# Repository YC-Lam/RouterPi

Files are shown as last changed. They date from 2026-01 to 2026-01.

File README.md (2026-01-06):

# RouterPi

A modular router development board based on the raspberry pi compute module 5.

Features:
- 2x 2.5G Ethernet Wan/Lan port
- 2x Gigabyte Ethernet Lan port
- M.2 E key connector for AP module
- RTC battery
- PWM fan connector
- SD card slot for compute module lite
- 12-24v input voltage

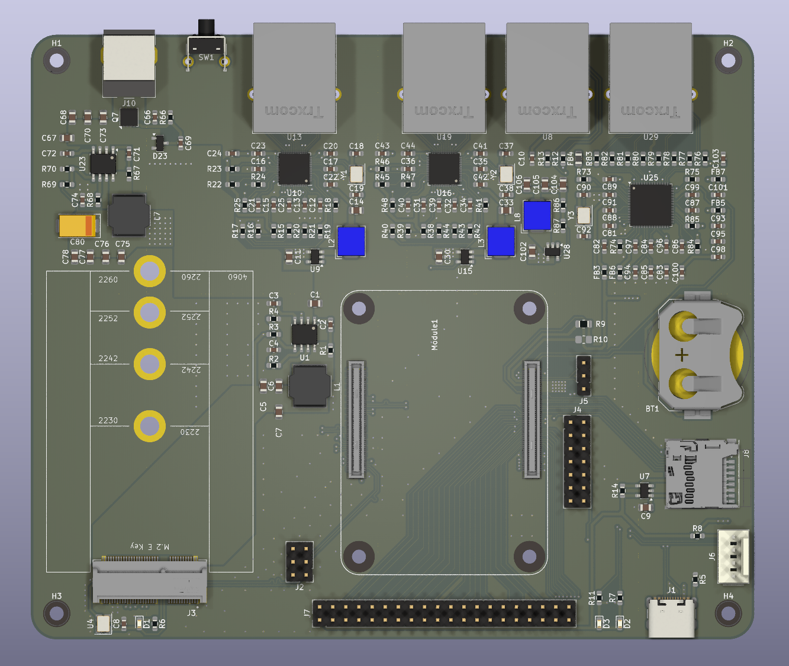
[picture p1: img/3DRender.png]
3D render


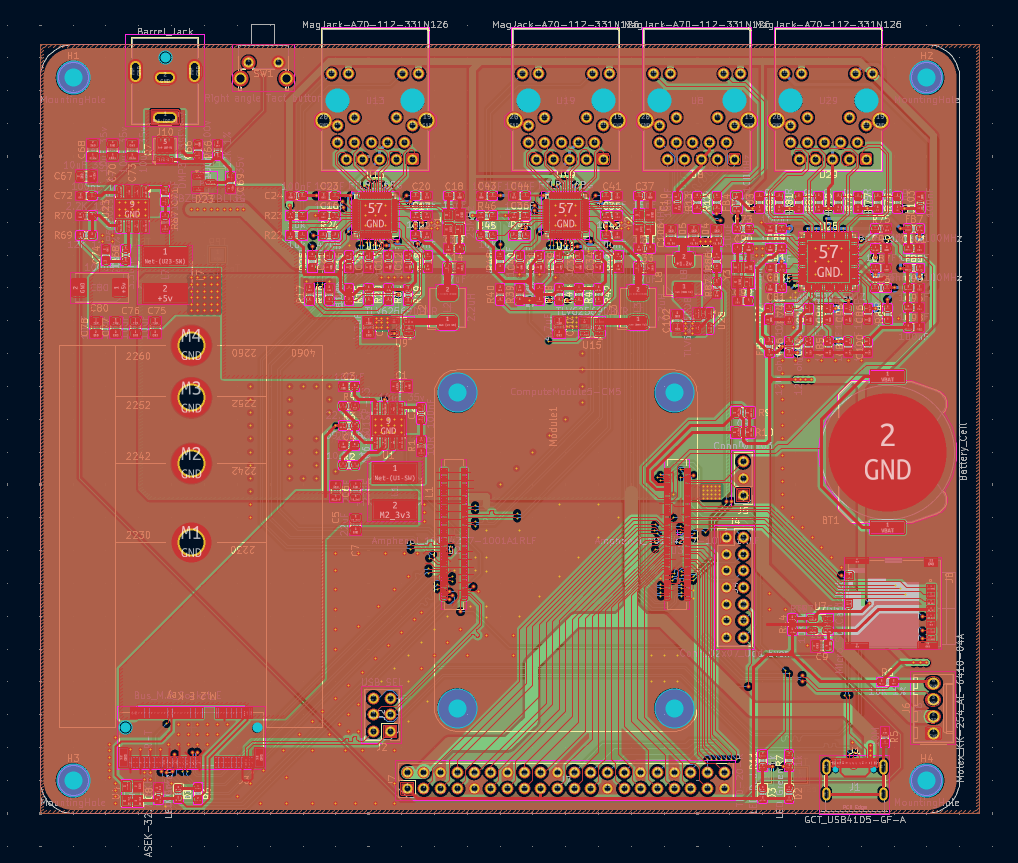
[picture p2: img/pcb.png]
PCB layout


# Design constraints
- minimal track width: 0.127 mm
- minimal clearance: 0.125 mm
- minimal via hole diameter: 0.3 mm
- minimal via ring diameter: 0.45 mm

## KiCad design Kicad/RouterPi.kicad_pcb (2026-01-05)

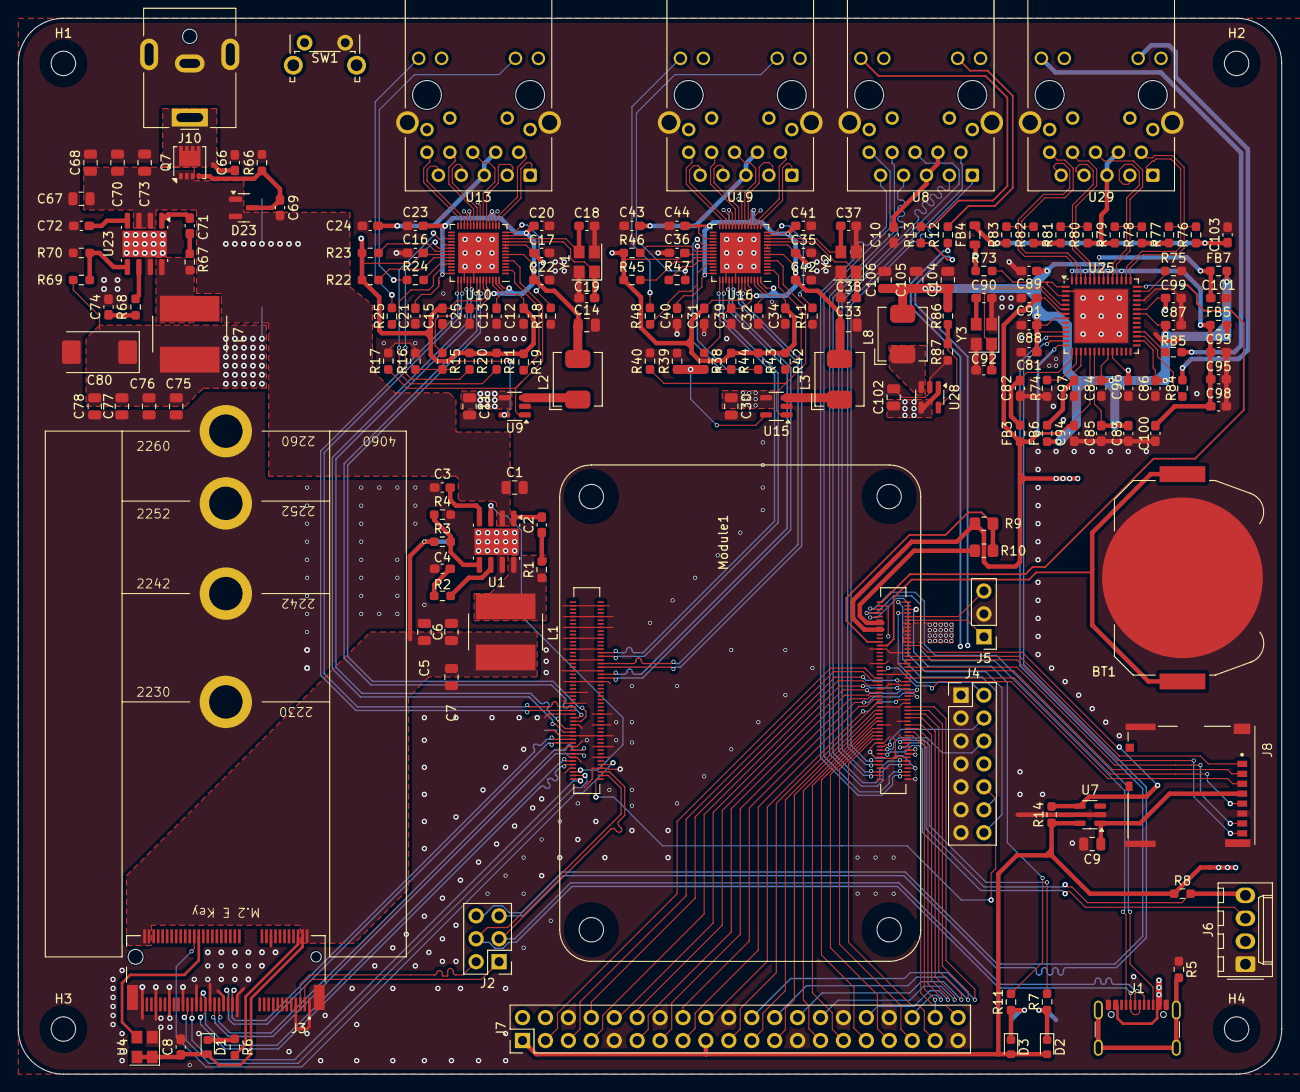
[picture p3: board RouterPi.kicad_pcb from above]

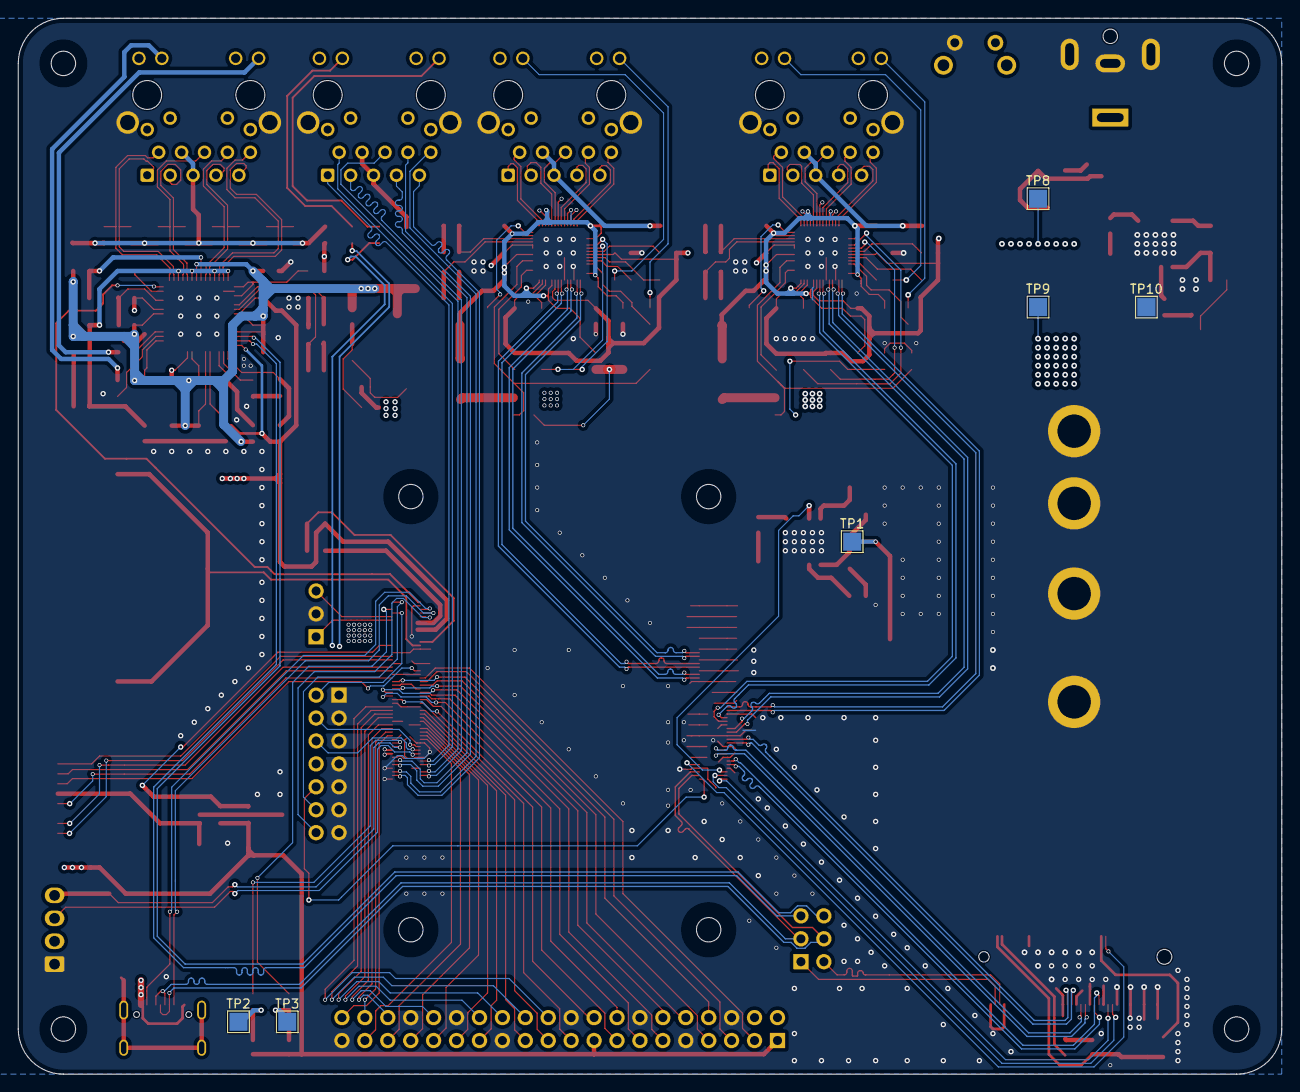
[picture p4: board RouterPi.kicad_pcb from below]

Board: 4 copper layers, 140.0 x 117.0 mm, 192 parts (6 on the bottom side), 199 nets.

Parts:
BT1: Battery_Cell; BatteryHolder_Keystone_3034_1x20mm
C1, C67, C68, C70, C73: 10uF 35v; C_0805_2012Metric
C2, C3, C8, C10, C12, C13, C15, C16, C17, C20, C21, C22, C23, C24, C25, C31, C32, C34, C35, C36, C39, C40, C41, C42, C43, C44, C71, C72, C81, C82, C83, C84, C85, C86, C87, C88, C89, C91, C93, C94, C95, C96, C97, C98, C99, C100, C101, C103: 100nF; C_0603_1608Metric_Pad1.08x0.95mm_HandSolder
C4: 2.7nF; C_0603_1608Metric_Pad1.08x0.95mm_HandSolder
C5, C6, C7: 22uF; C_0805_2012Metric
C9, C75, C76, C77, C78, C104, C105, C106: 10uF; C_0805_2012Metric
C11, C30, C102: 4.7uF; C_0805_2012Metric
C14, C33: 47uF; C_0805_2012Metric
C18, C19, C37, C38, C90, C92: 15pF; C_0603_1608Metric_Pad1.08x0.95mm_HandSolder
C66: 100nF 100v; C_0603_1608Metric_Pad1.08x0.95mm_HandSolder
C69: 100nF 35v; C_0603_1608Metric_Pad1.08x0.95mm_HandSolder
C74: 1.2nF; C_0603_1608Metric_Pad1.08x0.95mm_HandSolder
C80: 100uF; CP_EIA-7343-31_Kemet-D
D1, D2: LED Green; LED_0603_1608Metric
D3: LED Red; LED_0603_1608Metric
D23: MMBZ5242BLT3G; SOT-23
FB3, FB5, FB6, FB7: 120 ohms@100MHz; R_0603_1608Metric_Pad0.98x0.95mm_HandSolder
FB4: 220 ohms@100MHz; L_0805_2012Metric
H1, H2, H3, H4: MountingHole; MountingHole_2.7mm_M2.5_DIN965
J1: GCT_USB4105-GF-A; USB_C_Receptacle_GCT_USB4105-xx-A_16P_TopMnt_Horizontal
J2: USB SEL; PinHeader_2x03_P2.54mm_Vertical
J3: Bus_M.2_Socket_E; AMPHENOL_MDT420E03001
J4: Conn_02x07_Odd_Even; PinHeader_2x07_P2.54mm_Vertical
J5: Conn_01x03; PinHeader_1x03_P2.54mm_Vertical
J6: Molex_KK-254_AE-6410-04A; Molex_KK-254_AE-6410-04A_1x04_P2.54mm_Vertical
J7: THD-20-R; PinHeader_2x20_P2.54mm_Vertical
J8: Micro_SD_Card_Det; SDCARD_MOLEX_503398-1892
J10: Barrel_Jack; BarrelJack_CUI_PJ-063AH_Horizontal
L1, L7: 3.3uH; L_Bourns_SRN8040TA
L2, L3, L8: 2.2uH; L_Bourns_SRP5030CC
Module1: ComputeModule5-CM5; Raspberry-Pi-5-Compute-Module
Q7: DMP3013SFV-7; Diodes_PowerDI3333-8
R1, R67: 10R; R_0603_1608Metric_Pad0.98x0.95mm_HandSolder
R2: 10.5k 1%; R_0603_1608Metric_Pad0.98x0.95mm_HandSolder
R3: 69.8K 1%; R_0603_1608Metric_Pad0.98x0.95mm_HandSolder
R4: 22.1K 1%; R_0603_1608Metric_Pad0.98x0.95mm_HandSolder
R5: 10M; R_0603_1608Metric_Pad0.98x0.95mm_HandSolder
R6, R7, R11: 1k; R_0603_1608Metric_Pad0.98x0.95mm_HandSolder
R8, R14: 10K 1%; R_0603_1608Metric_Pad0.98x0.95mm_HandSolder
R9: 0R; R_0805_2012Metric_Pad1.20x1.40mm_HandSolder
R10: nf; R_0805_2012Metric_Pad1.20x1.40mm_HandSolder
R12, R13, R24, R25, R47, R48, R84, R85: 470R; R_0603_1608Metric_Pad0.98x0.95mm_HandSolder
R15, R38: 57.6k; R_0603_1608Metric_Pad0.98x0.95mm_HandSolder
R16, R39, R86, R87: 100k; R_0603_1608Metric_Pad0.98x0.95mm_HandSolder
R17, R19, R20, R21, R22, R23, R40, R42, R43, R44, R45, R46, R73: 10k; R_0603_1608Metric_Pad0.98x0.95mm_HandSolder
R18, R41: 2.49k; R_0603_1608Metric_Pad0.98x0.95mm_HandSolder
R66, R69: 12K 1%; R_0603_1608Metric_Pad0.98x0.95mm_HandSolder
R68: 20K 1%; R_0603_1608Metric_Pad0.98x0.95mm_HandSolder
R70: 2.2K 1%; R_0603_1608Metric_Pad0.98x0.95mm_HandSolder
R74: 12k 1%; R_0603_1608Metric_Pad0.98x0.95mm_HandSolder
R75: 8.06k 1%; R_0603_1608Metric_Pad0.98x0.95mm_HandSolder
R76, R77, R78, R79, R80, R81, R82, R83: 49.9R; R_0603_1608Metric_Pad0.98x0.95mm_HandSolder
SW1: Right angle Tact button; SW_Tactile_SPST_Angled_PTS645Vx58-2LFS
TP1, TP2, TP3, TP8, TP9, TP10: TestPoint; TestPoint_Pad_2.0x2.0mm
U1, U23: AP64501SP-13; SOIC-8-1EP_3.9x4.9mm_P1.27mm_EP2.95x4.9mm_Mask2.71x3.4mm
U2, U3: Amphenol_10164227-1001A1RLF; Amphenol_10164227-1001A1RLF_placeholder
U4: ASEK-32.768KHZ-L-R-T; Crystal_SMD_3225-4Pin_3.2x2.5mm
U7: RT9742GGJ5; SOT-23-5
U8, U13, U19, U29: MagJack-A70-112-331N126; TRJG0926HENL
U9, U15, U28: TLV62569DBVR; SOT-23-5
U10, U16: RTL8156BG; QFN-56_EP_6x6_Pitch0.35mm
U25: LAN7500-ABJZ; QFN-56-1EP_8x8mm_P0.5mm_EP5.9x5.9mm
Y1, Y2, Y3: 25MHz; Crystal_SMD_3225-4Pin_3.2x2.5mm

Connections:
/2.5G_ETHERNET_LAN/DVDD09: C33.1, C39.1, C40.1, C41.1, C42.1, C44.1, L3.2, R38.1, U16.7 (DVDD09), U16.13 (AVDD09), U16.18 (AVDD09), U16.24 (AVDD09), U16.31 (DVDD09), U16.42 (VDD09_USB), U16.52 (VDD09_USB), U16.56 (DVDD09)
/2.5G_ETHERNET_LAN/DVDD09_EN: R40.1, U15.1 (EN), U16.5 (POW_EXT_SWR)
/2.5G_ETHERNET_LAN/ETH_LEDG: R47.2, U16.38 (LED0/EEDI/SPISI)
/2.5G_ETHERNET_LAN/ETH_LEDY: R48.2, U16.39 (LED1/EESK/SPISCK)
/2.5G_ETHERNET_LAN/TRD0_N: U16.16 (MDIN0), U19.2 (TRD0-)
/2.5G_ETHERNET_LAN/TRD0_P: U16.15 (MDIP0), U19.1 (TRD0+)
/2.5G_ETHERNET_LAN/TRD1_N: U16.20 (MDIN1), U19.6 (TRD1-)
/2.5G_ETHERNET_LAN/TRD1_P: U16.19 (MDIP1), U19.3 (TRD1+)
/2.5G_ETHERNET_LAN/TRD2_N: U16.23 (MDIN2), U19.8 (TRD2-)
/2.5G_ETHERNET_LAN/TRD2_P: U16.22 (MDIP2), U19.7 (TRD2+)
/2.5G_ETHERNET_LAN/TRD3_N: U16.27 (MDIN3), U19.10 (TRD3-)
/2.5G_ETHERNET_LAN/TRD3_P: U16.26 (MDIP3), U19.9 (TRD3+)
/2.5G_ETHERNET_LAN/USB3_D_N: Module1.165 (USB3-1-D_N), U16.49 (DM)
/2.5G_ETHERNET_LAN/USB3_D_P: Module1.163 (USB3-1-D_P), U16.50 (DP)
/2.5G_ETHERNET_LAN/USB3_RXN: Module1.157 (USB3-1-RX_N), U16.47 (SSRXN)
/2.5G_ETHERNET_LAN/USB3_RXP: Module1.159 (USB3-1-RX_P), U16.46 (SSRXP)
/2.5G_ETHERNET_LAN/USB3_TXN: Module1.169 (USB3-1-TX_N), U16.44 (SSTXN)
/2.5G_ETHERNET_LAN/USB3_TXP: Module1.171 (USB3-1-TX_P), U16.43 (SSTXP)
/2.5G_ETHERNET_LAN/XIN: C37.1, U16.12 (CKXTAL1), Y2.3
/2.5G_ETHERNET_LAN/XOUT: C38.1, U16.11 (CKXTAL2), Y2.1
/2.5G_ETHERNET_WAN/DVDD09: C14.1, C20.1, C21.1, C22.1, C23.1, C25.1, L2.2, R15.1, U10.7 (DVDD09), U10.13 (AVDD09), U10.18 (AVDD09), U10.24 (AVDD09), U10.31 (DVDD09), U10.42 (VDD09_USB), U10.52 (VDD09_USB), U10.56 (DVDD09)
/2.5G_ETHERNET_WAN/DVDD09_EN: R17.1, U9.1 (EN), U10.5 (POW_EXT_SWR)
/2.5G_ETHERNET_WAN/ETH_LEDG: R24.2, U10.38 (LED0/EEDI/SPISI)
/2.5G_ETHERNET_WAN/ETH_LEDY: R25.2, U10.39 (LED1/EESK/SPISCK)
/2.5G_ETHERNET_WAN/TRD0_N: U10.16 (MDIN0), U13.2 (TRD0-)
/2.5G_ETHERNET_WAN/TRD0_P: U10.15 (MDIP0), U13.1 (TRD0+)
/2.5G_ETHERNET_WAN/TRD1_N: U10.20 (MDIN1), U13.6 (TRD1-)
/2.5G_ETHERNET_WAN/TRD1_P: U10.19 (MDIP1), U13.3 (TRD1+)
/2.5G_ETHERNET_WAN/TRD2_N: U10.23 (MDIN2), U13.8 (TRD2-)
/2.5G_ETHERNET_WAN/TRD2_P: U10.22 (MDIP2), U13.7 (TRD2+)
/2.5G_ETHERNET_WAN/TRD3_N: U10.27 (MDIN3), U13.10 (TRD3-)
/2.5G_ETHERNET_WAN/TRD3_P: U10.26 (MDIP3), U13.9 (TRD3+)
/2.5G_ETHERNET_WAN/USB3_D_N: Module1.136 (USB3-0-D_N), U10.49 (DM)
/2.5G_ETHERNET_WAN/USB3_D_P: Module1.134 (USB3-0-D_P), U10.50 (DP)
/2.5G_ETHERNET_WAN/USB3_RXN: Module1.130 (USB3-0-RX_P), U10.47 (SSRXN)
/2.5G_ETHERNET_WAN/USB3_RXP: Module1.128 (USB3-0-RX_N), U10.46 (SSRXP)
/2.5G_ETHERNET_WAN/USB3_TXN: Module1.142 (USB3-0-TX_P), U10.44 (SSTXN)
/2.5G_ETHERNET_WAN/USB3_TXP: Module1.140 (USB3-0-TX_N), U10.43 (SSTXP)
/2.5G_ETHERNET_WAN/XIN: C18.1, U10.12 (CKXTAL1), Y1.3
/2.5G_ETHERNET_WAN/XOUT: C19.1, U10.11 (CKXTAL2), Y1.1
/1000M_ETHERNET_LAN/+1.2v: C81.1, C83.1, C84.1, C85.1, C86.1, C87.1, C88.1, C89.1, C104.1, C105.1, C106.1, FB5.2, FB6.1, FB7.2, L8.2, R86.1, U25.8 (VDD12CORE), U25.11 (VDD12CORE), U25.20 (VDD12CORE), U25.23 (VDD12CORE), U25.30 (VDD12CORE), U25.36 (VDD12CORE), U25.49 (VDD12BIAS)
/1000M_ETHERNET_LAN/CT: C103.1, FB4.2, R76.1, R77.1, R78.1, R79.1, R80.1, R81.1, R82.1, R83.1, U29.4 (CT), U29.5 (CT)
/1000M_ETHERNET_LAN/ETH_LEDG: R84.2, U25.31 (GPIO0)
/1000M_ETHERNET_LAN/ETH_LEDY: R85.2, U25.32 (GPIO1)
/1000M_ETHERNET_LAN/TRD0_N: R76.2, U25.43 (TR0N), U29.2 (TRD0-)
/1000M_ETHERNET_LAN/TRD0_P: R77.2, U25.44 (TR0P), U29.1 (TRD0+)
/1000M_ETHERNET_LAN/TRD1_N: R78.2, U25.46 (TR1N), U29.6 (TRD1-)
/1000M_ETHERNET_LAN/TRD1_P: R79.2, U25.47 (TR1P), U29.3 (TRD1+)
/1000M_ETHERNET_LAN/TRD2_N: R80.2, U25.51 (TR2N), U29.8 (TRD2-)
/1000M_ETHERNET_LAN/TRD2_P: R81.2, U25.52 (TR2P), U29.7 (TRD2+)
/1000M_ETHERNET_LAN/TRD3_N: R82.2, U25.54 (TR3N), U29.10 (TRD3-)
/1000M_ETHERNET_LAN/TRD3_P: R83.2, U25.55 (TR3P), U29.9 (TRD3+)
/1000M_ETHERNET_LAN/USB2_D_N: J2.6, U25.12 (USBDM)
/1000M_ETHERNET_LAN/USB2_D_P: J2.5, U25.13 (USBDP)
/1000M_ETHERNET_LAN/VDD12A: C93.1, C95.1, C98.1, C100.1, FB5.1, U25.45 (VDD12A), U25.48 (VDD12A), U25.53 (VDD12A), U25.56 (VDD12A)
/1000M_ETHERNET_LAN/VDD12PLL: C101.1, FB7.1, U25.50 (VDD12PLL)
/1000M_ETHERNET_LAN/VDD12USBPLL: C97.1, FB6.2, U25.17 (VDD12USBPLL)
/1000M_ETHERNET_LAN/XIN: C90.1, U25.5 (XI), Y3.3
/1000M_ETHERNET_LAN/XOUT: C92.1, U25.6 (XO), Y3.1
/+3.3v: C12.1, C15.1, C16.1, C17.1, C31.1, C34.1, C35.1, C36.1, C91.1, C94.1, C96.1, C99.1, D2.2 (A), D3.2 (A), FB3.1, FB4.1, J7.1, J7.17, Module1.84 (+3.3v_(Output)), Module1.86 (+3.3v_(Output)), R8.1, R9.1, R14.1, R19.1, R20.1, R21.1, R22.1, R23.1, R42.1, R43.1, R44.1, R45.1, R46.1, R73.1, U7.5 (IN), U8.15 (LEDY_A), U8.17 (LEDG_A), U10.9 (AVDD33), U10.10 (AVDD33_XTAL), U10.17 (AVDD33), U10.21 (AVDD33), U10.25 (AVDD33), U10.36 (DVDD33), U10.51 (VDD33_USB), U10.55 (DVDD33_UPS), U13.15 (LEDY_A), U13.17 (LEDG_A), U16.9 (AVDD33), U16.10 (AVDD33_XTAL), U16.17 (AVDD33), U16.21 (AVDD33), U16.25 (AVDD33), U16.36 (DVDD33), U16.51 (VDD33_USB), U16.55 (DVDD33_UPS), U19.15 (LEDY_A), U19.17 (LEDG_A), U25.7 (VDDVARIO), U25.14 (VBUS_DET), U25.19 (VDDVARIO), U25.24 (VDDVARIO), U25.37 (VDDVARIO), U29.15 (LEDY_A), U29.17 (LEDG_A)
/+5v: C11.1, C30.1, C75.1, C76.1, C77.1, C78.1, C80.1, C102.1, J1.A4 (VBUS), J1.A9 (VBUS), J1.B4 (VBUS), J1.B9 (VBUS), J7.2, J7.4, L7.2, Module1.77 (+5v_(Input)), Module1.79 (+5v_(Input)), Module1.81 (+5v_(Input)), Module1.83 (+5v_(Input)), Module1.85 (+5v_(Input)), Module1.87 (+5v_(Input)), R69.1, TP9.1, U9.4 (VIN), U15.4 (VIN), U28.1 (EN), U28.4 (VIN)
/+12v: C1.1, C67.1, C68.1, C69.1, C70.1, C73.1, D23.1 (K), D23.2 (K), J6.2, Q7.1 (S), Q7.2 (S), Q7.3 (S), TP8.1, U1.2 (VIN), U23.2 (VIN), U23.3 (EN)
/CM5_GPIO ( Ethernet, GPIO, SDCARD)/+1.8v: Module1.88 (+1.8v_(Output)), Module1.90 (+1.8v_(Output)), R10.1
/CM5_GPIO ( Ethernet, GPIO, SDCARD)/BT_nDis: J5.3, Module1.91 (BT_nDisable)
/CM5_GPIO ( Ethernet, GPIO, SDCARD)/CC1: J1.A5 (CC1), Module1.94 (CC1)
/CM5_GPIO ( Ethernet, GPIO, SDCARD)/CC2: J1.B5 (CC2), Module1.96 (CC2)
/CM5_GPIO ( Ethernet, GPIO, SDCARD)/EEPROM_nWP: J4.4, Module1.20 (EEPROM_nWP)
/CM5_GPIO ( Ethernet, GPIO, SDCARD)/ETH_LEDG: Module1.17 (Ethernet_nLED2(3.3v)), R12.2
/CM5_GPIO ( Ethernet, GPIO, SDCARD)/ETH_LEDY: Module1.15 (Ethernet_nLED3(3.3v)), R13.2
/CM5_GPIO ( Ethernet, GPIO, SDCARD)/GPIO2: J7.3, Module1.58 (GPIO2)
/CM5_GPIO ( Ethernet, GPIO, SDCARD)/GPIO3: J7.5, Module1.56 (GPIO3)
/CM5_GPIO ( Ethernet, GPIO, SDCARD)/GPIO4: J7.7, Module1.54 (GPIO4)
/CM5_GPIO ( Ethernet, GPIO, SDCARD)/GPIO5: J7.29, Module1.34 (GPIO5)
/CM5_GPIO ( Ethernet, GPIO, SDCARD)/GPIO6: J7.31, Module1.30 (GPIO6)
/CM5_GPIO ( Ethernet, GPIO, SDCARD)/GPIO7: J7.26, Module1.37 (GPIO7)
/CM5_GPIO ( Ethernet, GPIO, SDCARD)/GPIO8: J7.24, Module1.39 (GPIO8)
/CM5_GPIO ( Ethernet, GPIO, SDCARD)/GPIO9: J7.21, Module1.40 (GPIO9)
/CM5_GPIO ( Ethernet, GPIO, SDCARD)/GPIO10: J7.19, Module1.44 (GPIO10)
/CM5_GPIO ( Ethernet, GPIO, SDCARD)/GPIO11: J7.23, Module1.38 (GPIO11)
/CM5_GPIO ( Ethernet, GPIO, SDCARD)/GPIO12: J7.32, Module1.31 (GPIO12)
/CM5_GPIO ( Ethernet, GPIO, SDCARD)/GPIO13: J7.33, Module1.28 (GPIO13)
/CM5_GPIO ( Ethernet, GPIO, SDCARD)/GPIO14: J7.8, Module1.55 (GPIO14)
/CM5_GPIO ( Ethernet, GPIO, SDCARD)/GPIO15: J7.10, Module1.51 (GPIO15)
/CM5_GPIO ( Ethernet, GPIO, SDCARD)/GPIO16: J7.36, Module1.29 (GPIO16)
/CM5_GPIO ( Ethernet, GPIO, SDCARD)/GPIO17: J7.11, Module1.50 (GPIO17)
/CM5_GPIO ( Ethernet, GPIO, SDCARD)/GPIO18: J7.12, Module1.49 (GPIO18)
/CM5_GPIO ( Ethernet, GPIO, SDCARD)/GPIO19: J7.35, Module1.26 (GPIO19)
/CM5_GPIO ( Ethernet, GPIO, SDCARD)/GPIO20: J7.38, Module1.27 (GPIO20)
/CM5_GPIO ( Ethernet, GPIO, SDCARD)/GPIO21: J7.40, Module1.25 (GPIO21)
/CM5_GPIO ( Ethernet, GPIO, SDCARD)/GPIO22: J7.15, Module1.46 (GPIO22)
/CM5_GPIO ( Ethernet, GPIO, SDCARD)/GPIO23: J7.16, Module1.47 (GPIO23)
/CM5_GPIO ( Ethernet, GPIO, SDCARD)/GPIO24: J7.18, Module1.45 (GPIO24)
/CM5_GPIO ( Ethernet, GPIO, SDCARD)/GPIO25: J7.22, Module1.41 (GPIO25)
/CM5_GPIO ( Ethernet, GPIO, SDCARD)/GPIO26: J7.37, Module1.24 (GPIO26)
/CM5_GPIO ( Ethernet, GPIO, SDCARD)/GPIO27: J7.13, Module1.48 (GPIO27)
/CM5_GPIO ( Ethernet, GPIO, SDCARD)/GPIO_VREF: Module1.78 (GPIO_VREF(1.8v/3.3v_Input)), R9.2, R10.2
/CM5_GPIO ( Ethernet, GPIO, SDCARD)/ID_SC: J7.28, Module1.35 (ID_SC)
/CM5_GPIO ( Ethernet, GPIO, SDCARD)/ID_SD: J7.27, Module1.36 (ID_SD)
/CM5_GPIO ( Ethernet, GPIO, SDCARD)/PMIC_ENABLE: J4.12, Module1.99 (PMIC_ENABLE)
/CM5_GPIO ( Ethernet, GPIO, SDCARD)/PWM: J6.4, Module1.19 (FAN_PWM), R8.2
/CM5_GPIO ( Ethernet, GPIO, SDCARD)/PWR_BUT: J4.14, Module1.92 (PWR_BUT), SW1.1
/CM5_GPIO ( Ethernet, GPIO, SDCARD)/SD_CLK: J8.5 (CLK), Module1.57 (SD_CLK)
/CM5_GPIO ( Ethernet, GPIO, SDCARD)/SD_CMD: J8.3 (CMD), Module1.62 (SD_CMD)
/CM5_GPIO ( Ethernet, GPIO, SDCARD)/SD_DAT0: J8.7 (DAT0), Module1.63 (SD_DAT0)
/CM5_GPIO ( Ethernet, GPIO, SDCARD)/SD_DAT1: J8.8 (DAT1), Module1.67 (SD_DAT1)
/CM5_GPIO ( Ethernet, GPIO, SDCARD)/SD_DAT2: J8.1 (DAT2), Module1.69 (SD_DAT2)
/CM5_GPIO ( Ethernet, GPIO, SDCARD)/SD_DAT3: J8.2 (DAT3/CD), Module1.61 (SD_DAT3)
/CM5_GPIO ( Ethernet, GPIO, SDCARD)/SD_PWR: C9.1, J8.4 (VDD), U7.1 (OUT)
/CM5_GPIO ( Ethernet, GPIO, SDCARD)/SD_PWR_ON: Module1.75 (SD_PWR_ON), R14.2, U7.4 (EN)
/CM5_GPIO ( Ethernet, GPIO, SDCARD)/SYNC_OUT: J4.6, Module1.18 (Ethernet_SYNC_OUT(3.3v))
/CM5_GPIO ( Ethernet, GPIO, SDCARD)/TACHO: J6.3, Module1.16 (FAN_TACHO)
/CM5_GPIO ( Ethernet, GPIO, SDCARD)/TRD0_N: Module1.10 (Ethernet_Pair0_N), U8.2 (TRD0-)
/CM5_GPIO ( Ethernet, GPIO, SDCARD)/TRD0_P: Module1.12 (Ethernet_Pair0_P), U8.1 (TRD0+)
/CM5_GPIO ( Ethernet, GPIO, SDCARD)/TRD1_N: Module1.6 (Ethernet_Pair1_N), U8.6 (TRD1-)
/CM5_GPIO ( Ethernet, GPIO, SDCARD)/TRD1_P: Module1.4 (Ethernet_Pair1_P), U8.3 (TRD1+)
/CM5_GPIO ( Ethernet, GPIO, SDCARD)/TRD2_N: Module1.9 (Ethernet_Pair2_N), U8.8 (TRD2-)
/CM5_GPIO ( Ethernet, GPIO, SDCARD)/TRD2_P: Module1.11 (Ethernet_Pair2_P), U8.7 (TRD2+)
/CM5_GPIO ( Ethernet, GPIO, SDCARD)/TRD3_N: Module1.5 (Ethernet_Pair3_N), U8.10 (TRD3-)
/CM5_GPIO ( Ethernet, GPIO, SDCARD)/TRD3_P: Module1.3 (Ethernet_Pair3_P), U8.9 (TRD3+)
/CM5_GPIO ( Ethernet, GPIO, SDCARD)/USBOTG: J4.10, Module1.101 (USB_OTG_ID)
/CM5_GPIO ( Ethernet, GPIO, SDCARD)/VBAT: BT1.1 (+), Module1.76 (VBAT)
/CM5_GPIO ( Ethernet, GPIO, SDCARD)/WL_nDis: J5.1, Module1.89 (WiFi_nDisable)
/CM5_GPIO ( Ethernet, GPIO, SDCARD)/nPWR_LED: Module1.95 (LED_nPWR), R11.2
/CM5_GPIO ( Ethernet, GPIO, SDCARD)/nRPIBOOT: J4.2, Module1.93 (nRPIBOOT)
/CM5_HighSpeed/M2_3v3: C5.1, C6.1, C7.1, C8.1, D1.2 (A), J3.2 (3.3V), J3.4 (3.3V), J3.72 (3.3V), J3.74 (3.3V), L1.2, R3.1, TP1.1, U4.1 (EN), U4.4 (VDD)
/CM5_HighSpeed/PCIE_CLK_N: J3.49 (REFCLKn0), Module1.112 (PCIe_CLK_N)
/CM5_HighSpeed/PCIE_CLK_P: J3.47 (REFCLKp0), Module1.110 (PCIe_CLK_P)
/CM5_HighSpeed/PCIE_PWR_EN: Module1.106 (PCIE_PWR_EN), U1.3 (EN)
/CM5_HighSpeed/PCIE_RX_N: J3.41 (PERp0), Module1.118 (PCIe_RX_N)
/CM5_HighSpeed/PCIE_RX_P: J3.43 (PERn0), Module1.116 (PCIe_RX_P)
/CM5_HighSpeed/PCIE_TX_N: J3.35 (PETp0), Module1.124 (PCIe_TX_N)
/CM5_HighSpeed/PCIE_TX_P: J3.37 (PETn0), Module1.122 (PCIe_TX_P)
/CM5_HighSpeed/PCIE_nCLKREQ: J3.53 (~CLKREQ0), Module1.102 (PCIe_nCLKREQ)
/CM5_HighSpeed/PCIE_nRST: J3.52 (~PERST0), Module1.109 (PCIe_nRST)
/CM5_HighSpeed/PCIE_nWAKE: J3.55 (~PEWAKE0), Module1.104 (PCIE_nWAKE)
/CM5_HighSpeed/USB2_M2_D_N: J2.2, J3.5 (USB_D-)
/CM5_HighSpeed/USB2_M2_D_P: J2.1, J3.3 (USB_D+)
/CM5_HighSpeed/USB2_N: J1.A7 (D-), J1.B7 (D-), J2.4, Module1.103 (USB2_N)
/CM5_HighSpeed/USB2_P: J1.A6 (D+), J1.B6 (D+), J2.3, Module1.105 (USB2_P)
/nEXTRST: Module1.100 (CAM_GPIO1), U25.42 (~RESET)
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
